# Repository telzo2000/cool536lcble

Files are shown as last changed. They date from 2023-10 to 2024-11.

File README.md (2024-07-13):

# cool536lcble

## What is cool536lcble?

The cool536lc key layout has been revised to create a 36-key keyboard that can be connected wirelessly via Bluetooth.

<br>

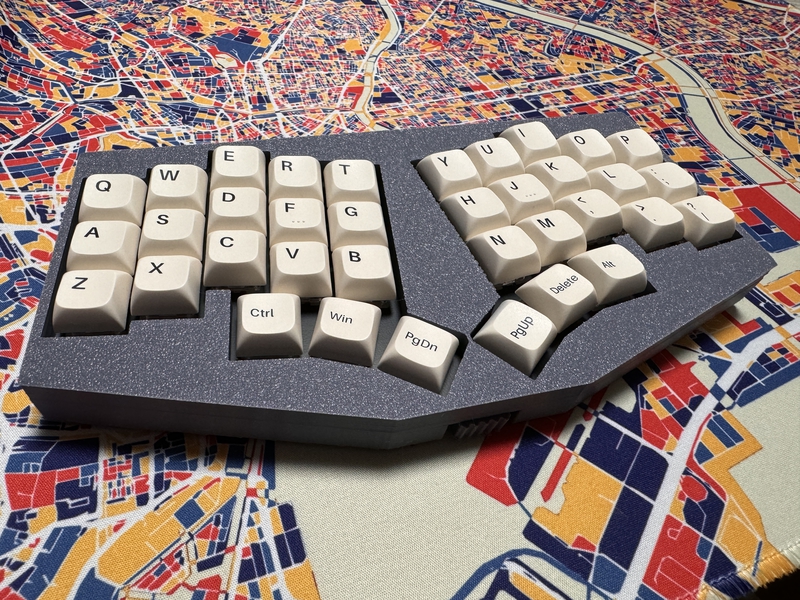
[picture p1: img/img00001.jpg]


## firmware

https://github.com/telzo2000/cool536lcble/tree/main/firmware

 cool536lc run QMK_firmware,use BLE Micro Pro.

## buildguide

https://github.com/telzo2000/cool536lcble/blob/main/buidguide_for_cool536lcble.md

## Parts list

| No. | Patrs | Quantity | remarks | Suppliers | Cost |
|--|--|--|--|--|--|
|番号|名前|数|備考|調達先|参考価格（送料込）|<br>
|1|PCB|1|36key |[elecrow](https://www.elecrow.com)<br>[JLCPCB](https://jlcpcb.com)<br>[ALLPCB](https://www.allpcb.com)|５枚で20〜30ドル|<br>
|2|Switch Plate|1||[elecrow](https://www.elecrow.com)<br>[JLCPCB](https://jlcpcb.com)<br>[ALLPCB](https://www.allpcb.com)|５枚で20〜30ドル|<br>
|3|Ble Micro|1||[遊舎工房](https://shop.yushakobo.jp/products/ble-micro-pro?_pos=1&_sid=c1171a4b2&_ss=r)<br>[のぎすけ屋](https://booth.pm/ja/items/1177319)|4500〜4950円|
|4|ボタン電池ホルダー|1|HU1632|[モノタロウ](https://www.monotaro.com/p/8835/2765/)<br>|263円|
|5|水平スライドスイッチ|1||[遊舎工房](https://shop.yushakobo.jp/products/5624?_pos=1&_sid=f65b70e3c&_ss=r)|110円|
|6|チップ積層セラミックコンデンサー |1|100μF6.3V F 3216|[秋月電子](https://akizukidenshi.com/catalog/g/g102151/)|10個入り200円|
|7|Swith socket<br>スイッチソケット|36|cherry MX互換|[遊舎工房](https://yushakobo.jp)<br>[Talp Keyboard](https://talpkeyboard.net)<br>[Daily Craft Keyboard](https://shop.dailycraft.jp)等|10個で187円程度|
|8|Diode<br>ダイオード|36|リードタイプでもSMDでも可|[遊舎工房](https://yushakobo.jp)<br>[Talp Keyboard](https://talpkeyboard.net)<br>[Daily Craft Keyboard](https://shop.dailycraft.jp)等|100個で220円程度から|
|9|Tadpole|6|代用品募集中|[Geon Works](https://geon.works/products/tadpole?variant=42514434752675)|14個で６ドルまたは200個で45ドル（送料55ドル!）|
|10|TopCase|1|3D Print|||
|11|BottomCase|1|3D Print||
|12|Switch Parts|1|3D Print||

In addition, you will need a USB cable, keycaps, etc.
<br>
この他に、USBケーブル、キーキャップ等が必要です。
<br>

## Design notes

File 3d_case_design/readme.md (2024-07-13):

# 3D case

The v100 model is an older design. The key layout is different from ver.1.4.
<br>

## LIsence

The 3D case design cannot be altered without my permission. 
<br>
I give permission to use it as is.
<br>

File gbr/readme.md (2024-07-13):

# gbr data

v110 is old. Gerber data with the same key layout as cool536lc.
<br>
The latest version will not be released for a while.

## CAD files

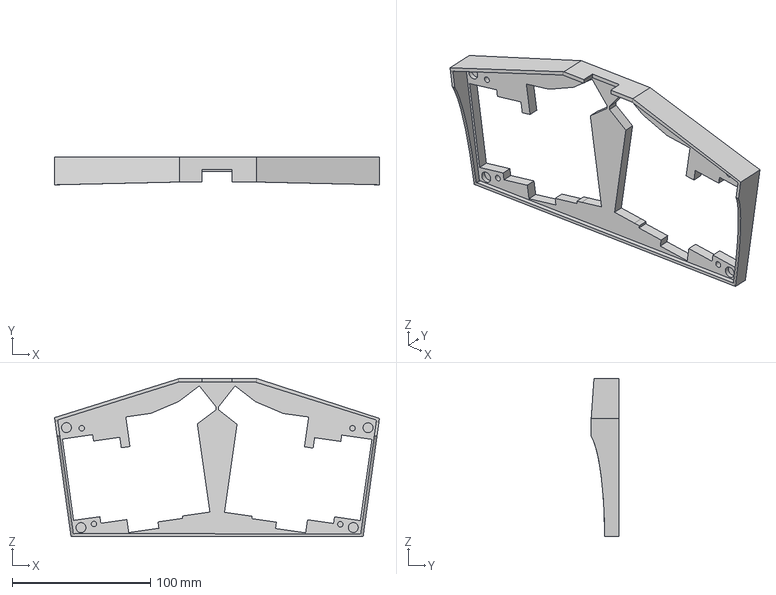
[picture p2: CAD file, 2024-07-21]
3d_case_design/v140_model/stl/cool536lcble_topcase_for_cnc v2.step
235.4 x 20.0 x 114.5 mm

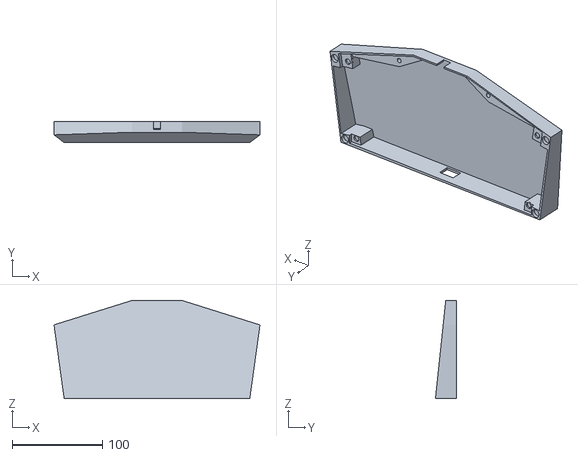
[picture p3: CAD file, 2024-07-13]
3d_case_design/v140_model/stl/cool536lcble_bottom v9.stl
228.6 x 23.5 x 108.8

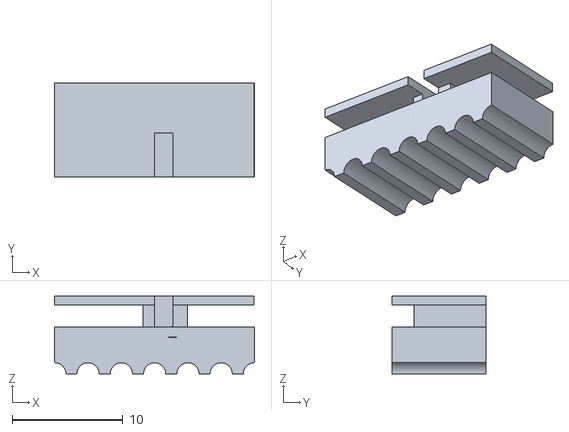
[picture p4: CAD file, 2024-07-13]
3d_case_design/v140_model/stl/switch_knob_cool536lcble v8.stl
18.0 x 8.50 x 7.01

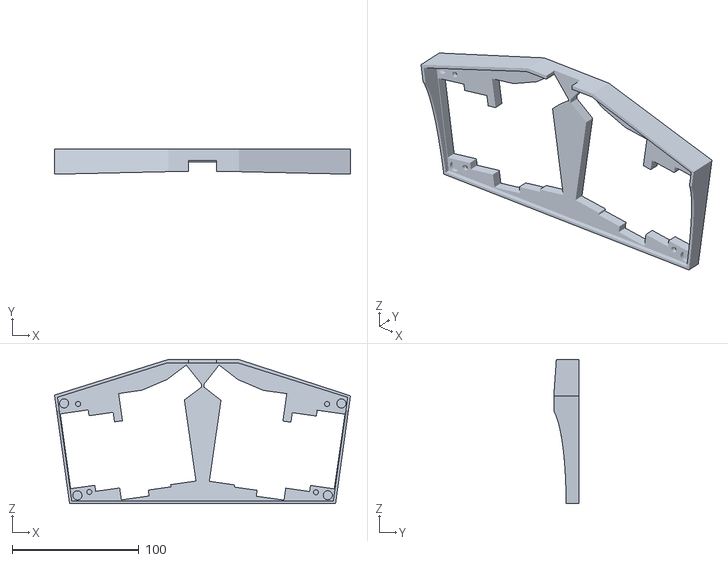
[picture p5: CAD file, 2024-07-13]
3d_case_design/v140_model/stl/cool536lcble_topcase v6.stl
233.1 x 20.0 x 113.5

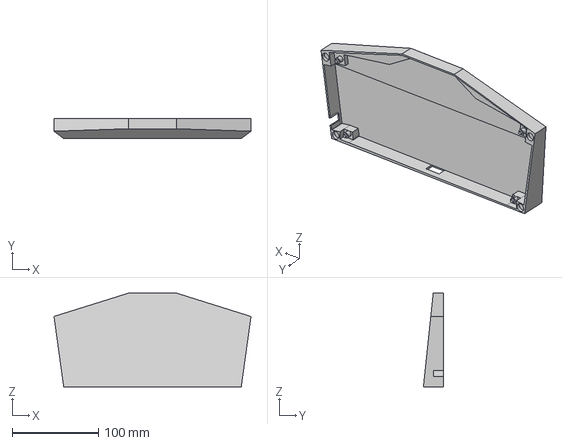
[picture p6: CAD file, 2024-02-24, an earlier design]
3d_case_design/v100_model/step/cool536lcble_bpttom_newversion v12.step
228.6 x 23.5 x 108.8 mm

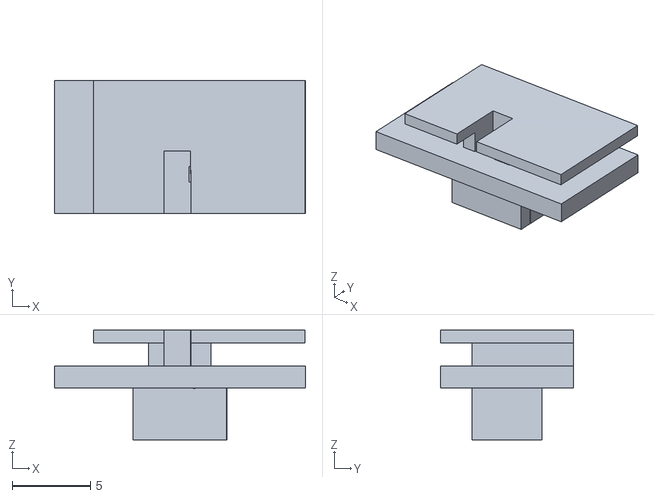
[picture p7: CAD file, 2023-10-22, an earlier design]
3d_case_design/v100_model/stl/switchknobcool536lcblev6.stl
16.0 x 8.50 x 7.00

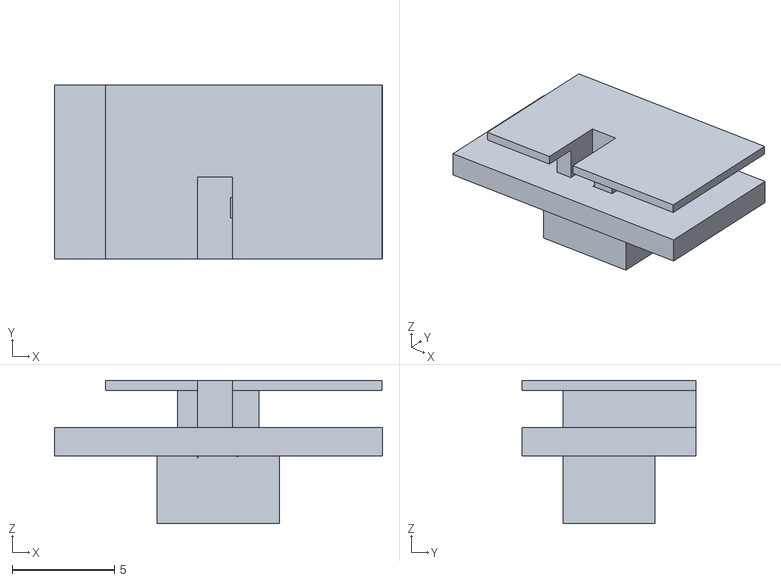
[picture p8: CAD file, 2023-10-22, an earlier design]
3d_case_design/v100_model/stl/switchknobcool536lcblev5.stl
16.0 x 8.50 x 7.00

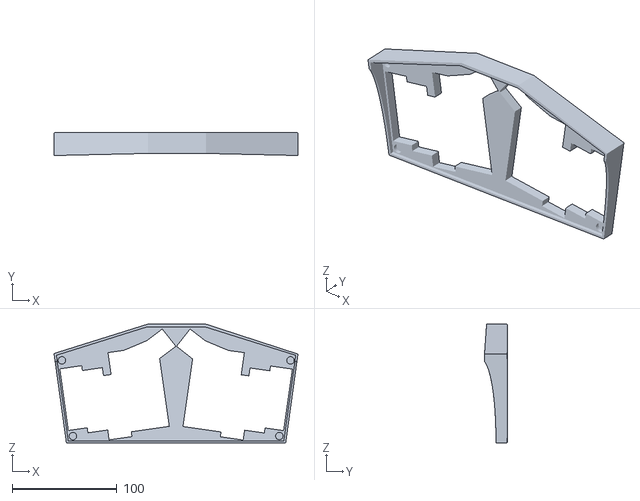
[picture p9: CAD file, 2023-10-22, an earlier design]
3d_case_design/v100_model/stl/cool536lcbletopv9.stl
233.1 x 22.0 x 113.5

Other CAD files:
3d_case_design/v100_model/stl/cool536lcblebottomv9.stl
3d_case_design/v100_model/stl/cool536lcble_bpttom_newversion v12.stl
3d_case_design/v140_model/stl/cool536lcble_topcase_for_cnc v2.stl

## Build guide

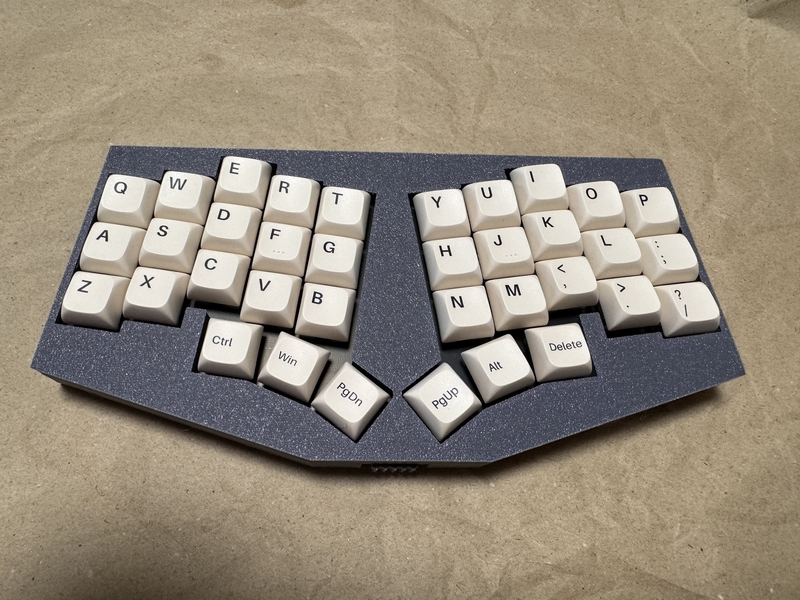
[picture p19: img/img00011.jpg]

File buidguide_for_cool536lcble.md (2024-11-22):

## Build guide

## Build 1

### 1 Diode soldering

Solder the diodes to the back of PCB.
<br>
PCBの裏面にダイオードのハンダ付けをします。
<br>
There are lead type and SMD diodes.
<br>
ダイオードはリードタイプか、SMDがあります。
<br>
Here, we will explain the lead type soldering.
<br>
ここでは、リードタイプのハンダ付けの説明をします。
<br>

Use a lead bender to bend the legs of the diode.
<br>
リードベンダーを使い、ダイオードの足を曲げます。
<br>
Insert the diode into the board.
<br>
ダイオードを基板に挿しこみます。
<br>

Please pay attention to the orientation of the diode.
<br>
ダイオードの向きに注意してください。
<br>

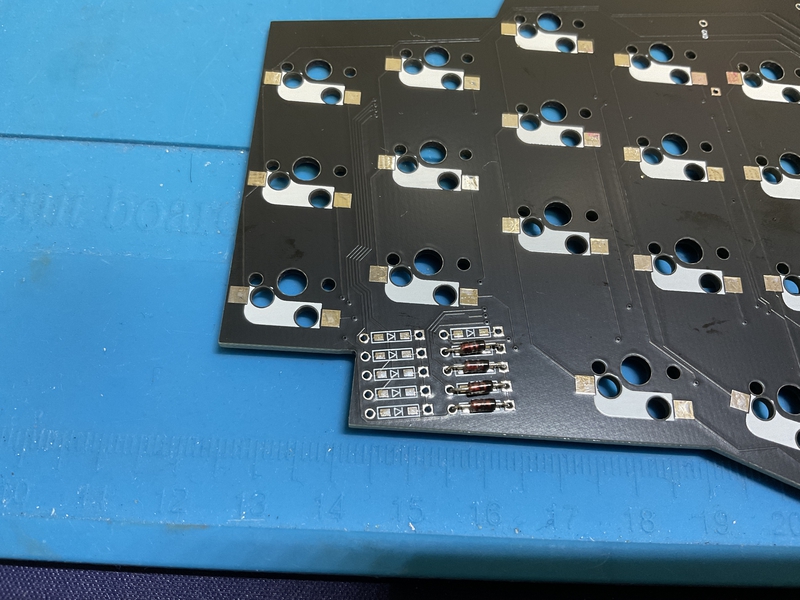
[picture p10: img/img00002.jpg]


Secure the diode with masking tape, then face up.
<br>
マスキングテープでダイオードを固定してから、表面を上にします。
<br>
Solder the protruding legs.
<br>
はみ出ている足部分に、ハンダ付けをします。
<br>
After soldering, use nippers to cut off the protruding legs.
<br>
はんだ付けが終わったら、はみ出ている足をニッパーで切り取ってください。
<br>



[８倍速　Diodeハンダ付け動画](https://youtu.be/Yaodh2-XxV4)

<br>
<br>

### 2 Soldering switch sockets

Solder the switch sockets on the back side.
<br>
裏面にスイッチソケットのハンダ付けをします。
<br>

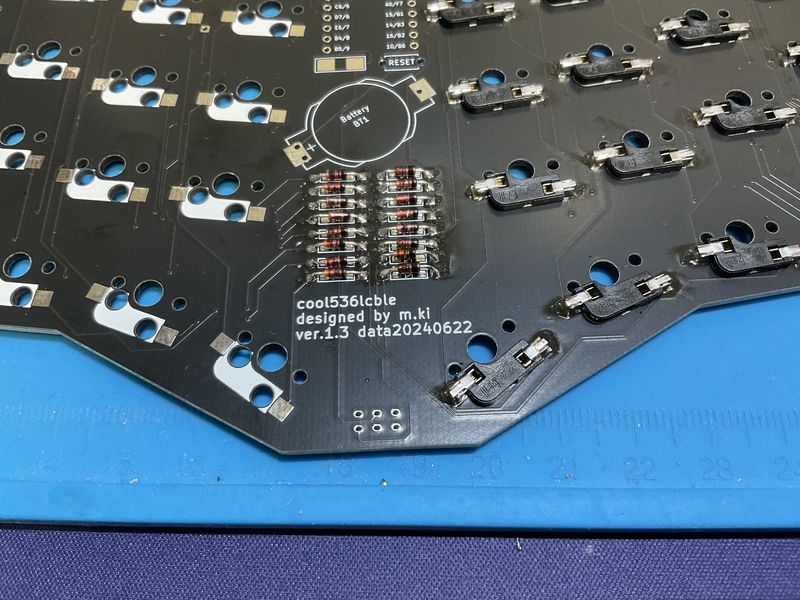
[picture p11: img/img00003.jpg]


[８倍速　Switch socketハンダ付け動画](https://youtu.be/E__mHvmIXQo)

<br><br>

### 3 Soldering the capacitor

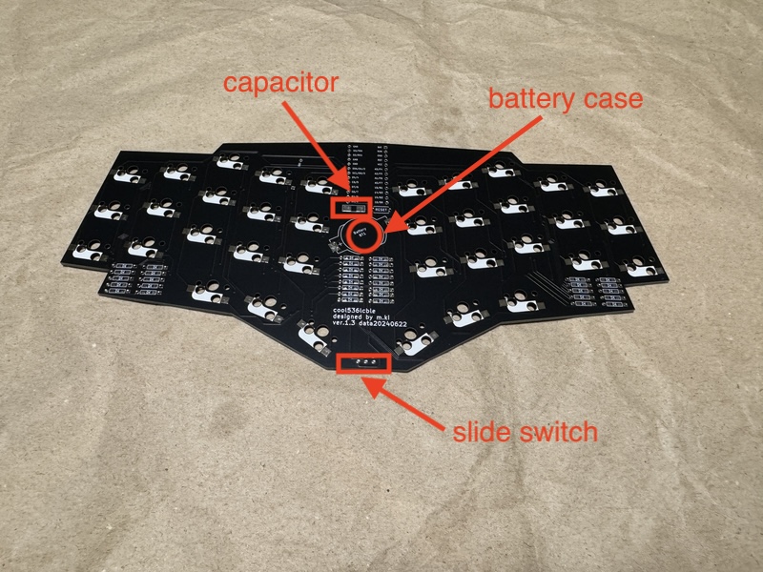
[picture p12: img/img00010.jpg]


Solder the [capacitor](https://akizukidenshi.com/catalog/g/gP-02151/).
<br>
[コンデンサー](https://akizukidenshi.com/catalog/g/gP-02151/)をハンダ付けします。
<br>

First, apply solder to the terminal on one side. Then, place the capacitor, melt the solder, and fix it.
<br>
最初に、片側の端子にハンダを盛ります。そして、コンデサーを置き、ハンダを溶かして、固定します。
<br>

Next, melt and pour solder into the other terminal and attach the capacitor. Please fix it.
<br>
次に、もう片側の端子にハンダを溶かして、流し込んで、コンデンサーを。固定してください。
<br>
<br>

[コンデンサのはんだ付け作業の動画](https://youtu.be/8CFiDMtg21s)

### 4 Soldering the slide switch

Insert the [slide switch](https://shop.yushakobo.jp/products/5624?variant=45044666007783) from the back side of the PCB and solder the front side. Please remove the protruding legs.
<br>
[スライドスイッチ](https://shop.yushakobo.jp/products/5624?variant=45044666007783)はPCBの裏面から挿入して、表面をハンダ付けします。はみ出た足は、切り取ってください。
<br>

[スライドスイッチのはんだ付けの作業動画](https://youtu.be/5nkRklibay4)

### 5 Soldering the battery case



[Battery box](https://www.monotaro.com/p/8835/2765/) is inserted from the back of the PCB and soldered on the front side. The protruding legs. Please cut it out.
<br>
[電池ボックス](https://www.monotaro.com/p/8835/2765/)は、PCB裏面から挿入して、表面をハンダ付けします。はみ出た足は。切り取ってください。





### 6 (Option) Solering the reset switch



Actually, it's not necessary. If you are an cool536lcble and are trying to install a WPRO microw without buying a Ble Micro Pro, you will need a reset switch.
<br>

実は必要ありません。もし、あなたが cool536lcbleなのに、Ble Micro Proをおごることをせずに、ただのpro micro取り付けようとするならば、リセットスイッチは必要でしょうね。
<br>



[リセットスイッチのはんだ付けの作業動画](https://youtu.be/Pl24Exfh8b8)

### 7 Ble Micro Pro



Please prepare [Ble Micor Pro](https://shop.yushakobo.jp/products/ble-micro-pro?_pos=1&_sid=192f46387&_ss=r).
<br>
[Ble Micor Pro](https://shop.yushakobo.jp/products/ble-micro-pro?_pos=1&_sid=192f46387&_ss=r)を用意してください。
<br>

If it is a 12-pin con-through, install it as shown in the image. Then insert the Ble Micro Pro.

12ピンコンスルーであれば、画像のように、取り付けてください。そして、Ble Micro Proを挿入してください。
<br>





### 8 Please insert the batteries.



Insert the CR1632 battery into the battery box.
<br>
CR1632電池を電池ボックスに挿入してください。
<br>


### 9 Firmware

The explanation is posted [here](https://sizu.me/m_ki/posts/x1mh846sx3zd).

<br>

[ここ](https://sizu.me/m_ki/posts/x1mh846sx3zd)に説明を載せています。
<br><br>

"6 Installing QMK_Firmware on Ble Micro pro" from [this site](https://github.com/telzo2000/cool836qalble/blob/main/build_guide_cool836qalble.md). please refer.
<br>
[このサイト](https://github.com/telzo2000/cool836qalble/blob/main/build_guide_cool836qalble.md)の「6 Instorlling QMK＿Firmware on Ble Micro pro」を。参考にしてください。
<br>

### Build 2(case)

### 1 Case

Fix the [magnets](https://www.amazon.co.jp/gp/product/B09B7BSXC4/ref=ppx_yo_dt_b_asin_title_o02_s00?ie=UTF8&th=1) to the five dents inside the case with an adhesive or the like. There are 4 in the top case and 4 in the bottom case for a total of 8.Please pay attention to the polarity of the magnet. Make sure the top case and bottom case are magnetically attached.
<br>
ケースの内側にある４つの凹みに[磁石](https://www.amazon.co.jp/gp/product/B09B7BSXC4/ref=ppx_yo_dt_b_asin_title_o02_s00?ie=UTF8&th=1)を接着剤などで固定します。トップケースに４箇所、ボトムケースに４箇所の合計８箇所です。
極性に注意してください。トップケースとボトムケースが磁力で付くようにしてください。
<br>
<br>
Due to the characteristics of 3D printed matter, the top case and bottom case may be able to interlock and be fixed without using magnets.
<br>
3Dプリンタでの印刷物の特性上、磁石を付けなくても、トップケースとボトムケースが噛み合わさり、固定できることがあります。
<br>
<br>

Insert the 4 Tadpoles into the 4 locations on the switch plate from below. Also, insert two Tadpoles into the bottom case from above in two places.
<br>
Tadpole４個をスイッチプレートの４箇所に、下から差し込みます。また、Tadpole２個を、ボトムケースの２箇所に上から差し込みます。

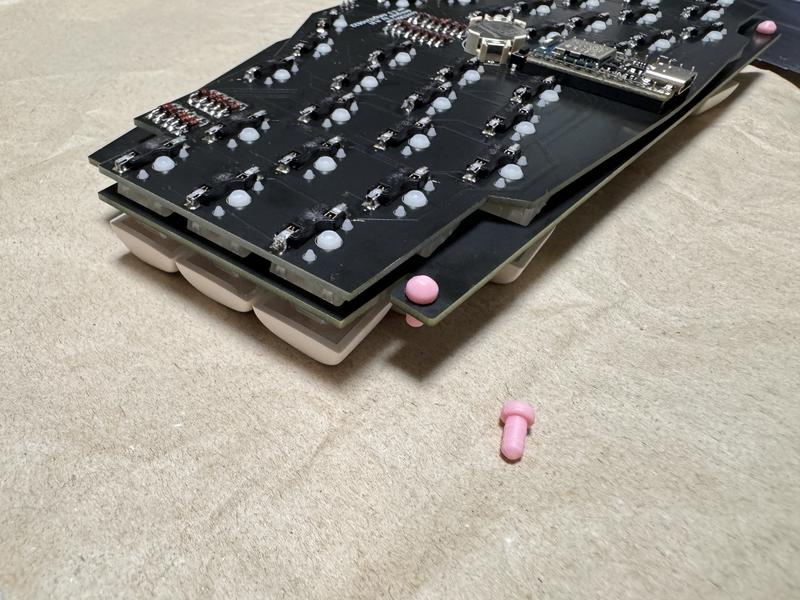
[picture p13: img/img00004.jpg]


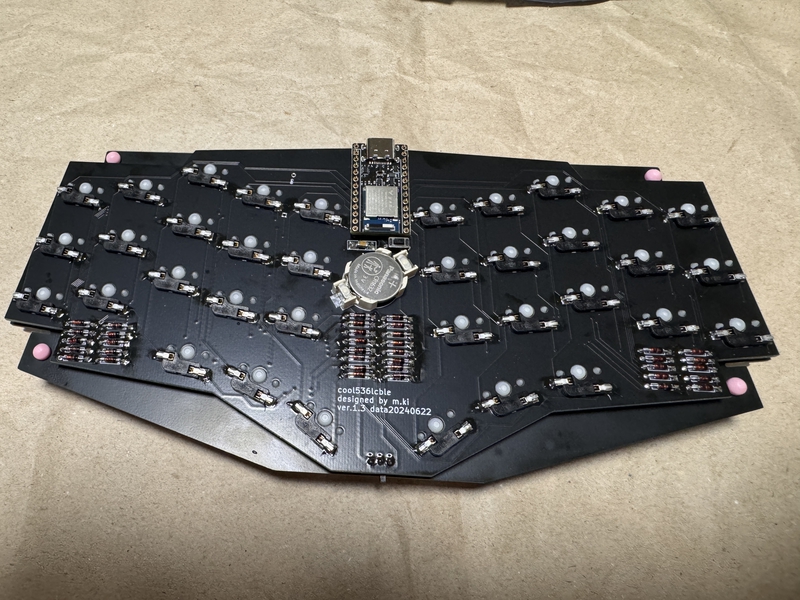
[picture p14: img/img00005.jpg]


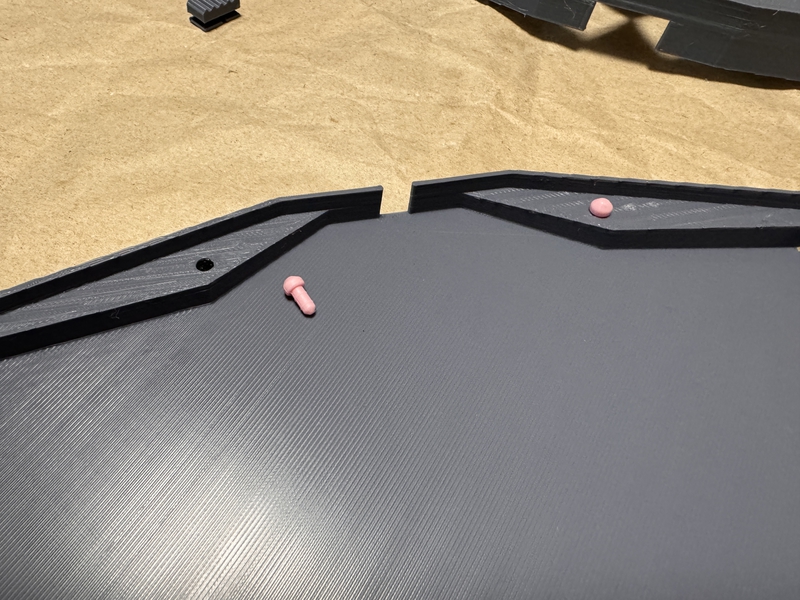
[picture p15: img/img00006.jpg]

<br>
<br>
Insert the switch knob into the recessed part in front of the bottom case.
<br>
ボトムケース手前の凹部分に、スイッチノブを挟みます。

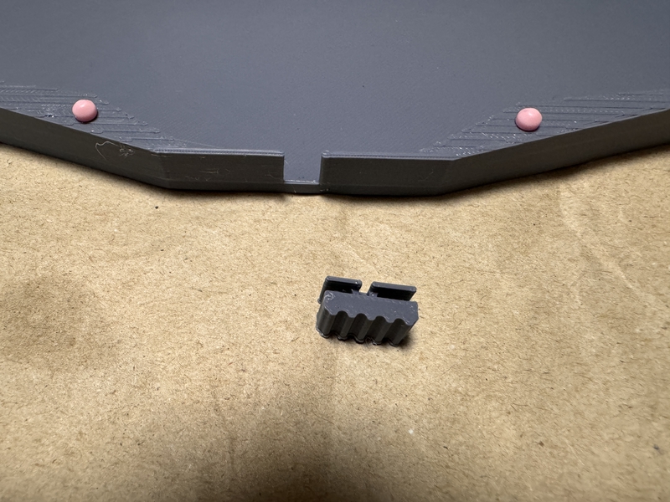
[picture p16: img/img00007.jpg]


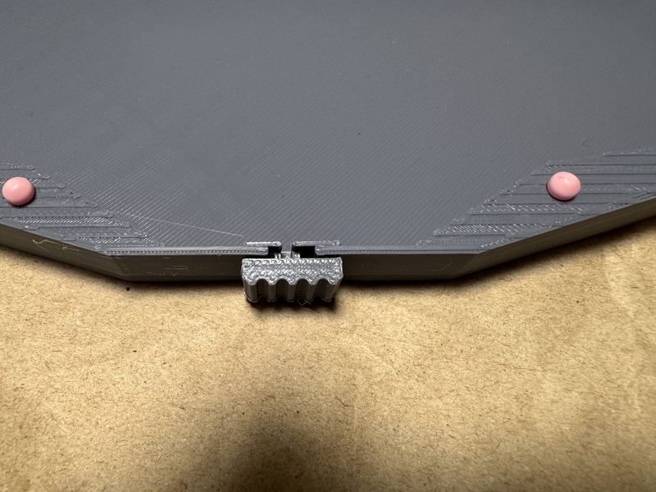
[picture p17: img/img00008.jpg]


<br>
<br>
Insert the switch plate and PCB between the top case and bottom case, secure them with magnets, and you're done.
<br>
トップケースとボトムケースの間にスイッチプレートとPCBを挟み込むように入れて、磁石で固定すれば完成です。

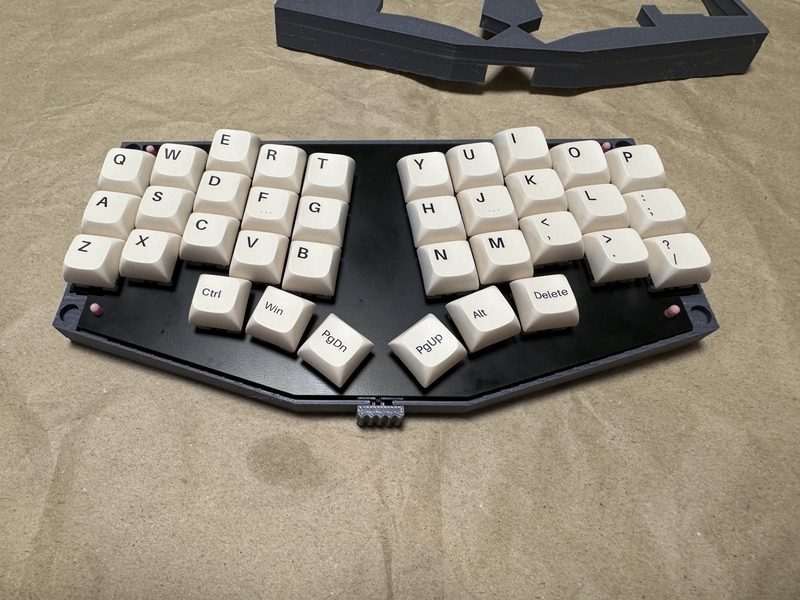
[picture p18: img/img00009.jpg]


<br>

Welcome to the world of 36 keys.
<br>
36キーの世界へようこそ。
<br>
